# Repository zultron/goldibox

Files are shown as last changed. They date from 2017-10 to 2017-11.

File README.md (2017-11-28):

# Goldibox.  Not too hot, not too cold.

The Goldibox is an insulated box that maintains temperature using a
thermoelectric device and a controller.  Originally conceived to
incubate biological organisms that thrive best within a particular
maximum/minimum temperature range, it can both heat and cool to avoid
extremes, but still allow variability within a habitable "Goldilocks
zone":  not too hot, not too cold, but just right.

The Goldibox's smart controller exposes a remote, network-connected
graphical interface for setting temperatures, checking current state,
and viewing history through time series graphs.  Anyone may modify the
open-source control to add new features.

## Components

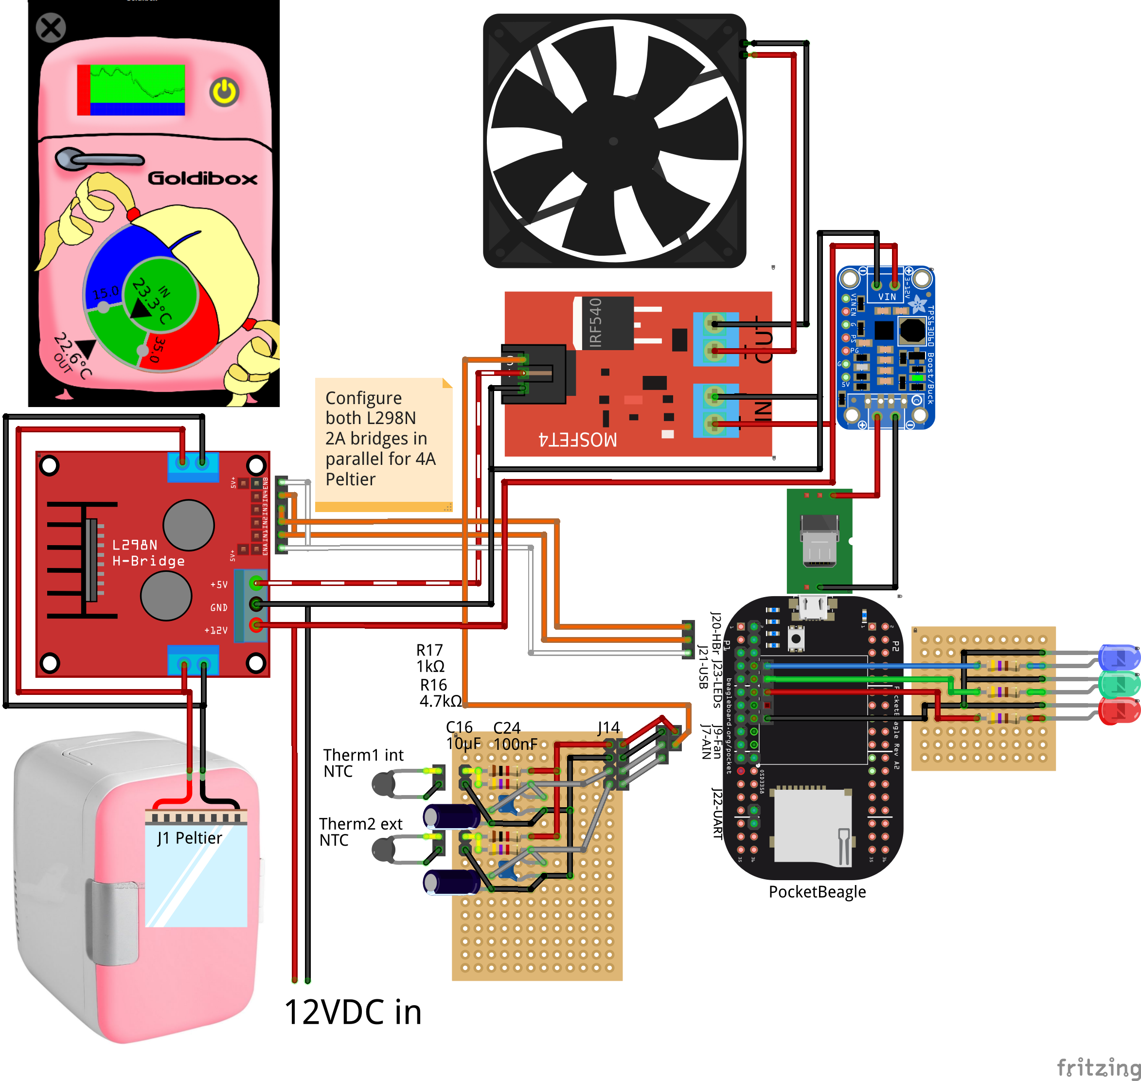
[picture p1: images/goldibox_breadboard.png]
Goldibox


The Goldibox is built from a portable fridge with a [Peltier
junction][wiki-peltier] that can be switched either to cool or to heat
by reversing the input voltage.

The Goldibox controller, a tiny [PocketBeagle][pocketbeagle] computer
that runs Debian, fits in the cramped space next to the Peltier
junction fan and heat sink.  It senses internal and external
temperatures through a pair of thermistors attachd to its analog
inputs, and it switches the Peltier junction and fan through an
H-bridge and a MOSFET, respectively, connected through GPIO digital
output pins.  See `BOM.md` for a list of hardware components, and
`fritzing/goldibox.fzz` for connecting them.

The [Machinekit][machinekit] software runs the configuration in this
repository:  some python user-space components in the `bin/`
directory, and HAL configuration in the `hal/` directory.  The
`goldibox-control` component decides whether to switch the Peltier
junction to cool, heat, or off, depending on the measured temperature
compared to the user's Goldilocks temperature settings.  The
`goldibox-logger` component logs to a RRD database, from which time
series charts are generated.

The `goldibox-control` component exposes a remote UI, used by the
`MachinekitClient` software, which can be downloaded for Android from
the Google Play store, and for Linux, Mac OS X and Windows directly
from the [QtQuickVCP][qqvcp] project.  The configuration in the `qml`
directory defines the simple user interface with thermostat controls
for the "too hot" and "too cold" zones, readouts for internal and
external temperature, a power control to enable and disable the
Goldibox, and a time series chart showing temperatures over the last
day.

# Running

Follow the instructions at [machinekit.io][machinekit] to download
and install a mini-SD card image with Machinekit.

Log into the BeagleBone, clone this repository, and `cd` into the
repository directory.

On the PocketBeagle, start the Goldibox control from the command line
(load the overlay file for non-system installs):

    # Install minimal apache and other config
    sudo make install MININSTALL=1
    # Start control
    bin/goldibox -o

The Goldibox should now be ready for control.  Start the
[MachinekitClient][qqvcp] and open the Goldibox app.

Alternatively, run a Goldibox simulated control and GUI in a Docker
container from the command line:

    # Start the container
    docker/qqvcp.sh
    # Install minimal apache and other config
    sudo make install MININSTALL=1
    # Start control
    bin/goldibox &
    # Start GUI
    MachinekitClient &

The Goldibox may be installed to the system so that it is run at every
boot:

    sudo make install
    sudo systemctl daemon-reload
    sudo systemctl enable goldibox
    sudo systemctl start goldibox

The `apache2` package must be installed and the web server running for
the time-series chart to work.

# Installing the PocketBeagle

See the jumble of notes in [NOTES.md](NOTES.md)

[wiki-peltier]: https://en.wikipedia.org/wiki/Thermoelectric_cooling
[pocketbeagle]: https://beagleboard.org/pocket
[machinekit]: http://www.machinekit.io/
[qqvcp]: https://github.com/qtquickvcp/QtQuickVcp

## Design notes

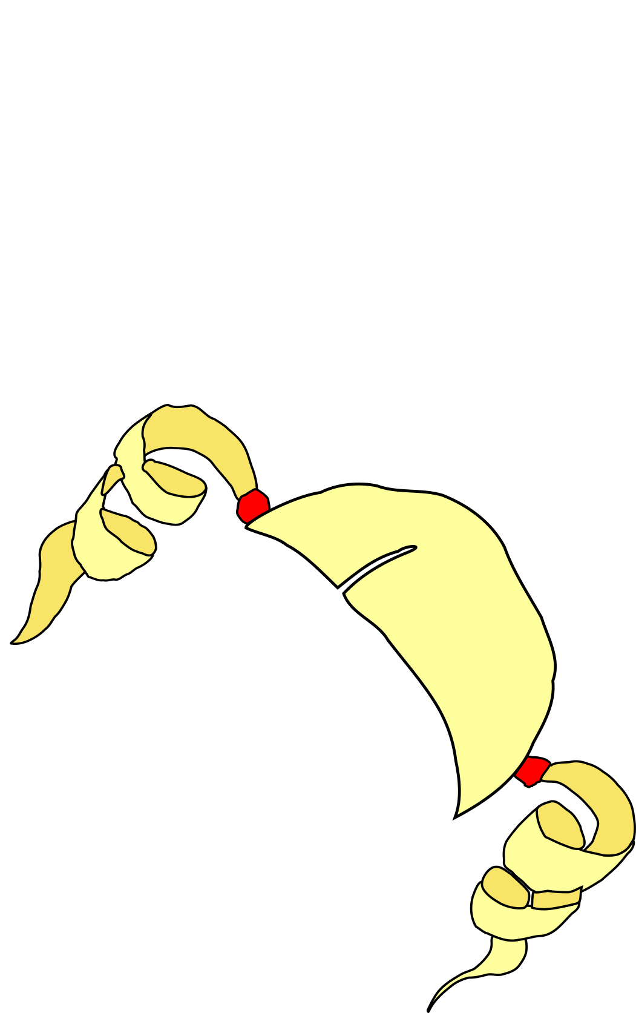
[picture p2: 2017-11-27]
qml/goldibox-remote/assets/locks.png

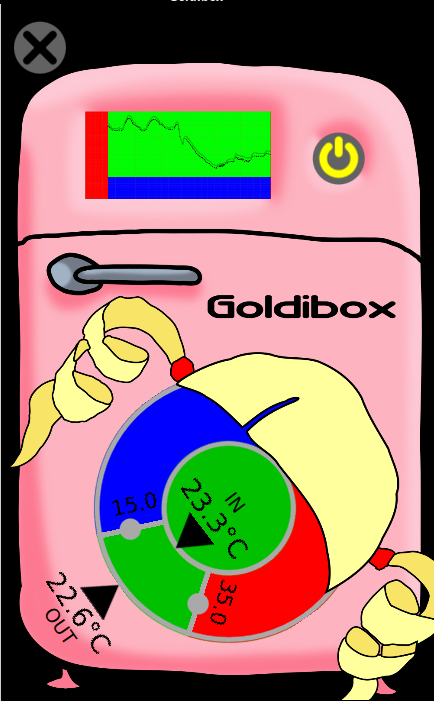
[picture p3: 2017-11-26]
images/gui-capture.png

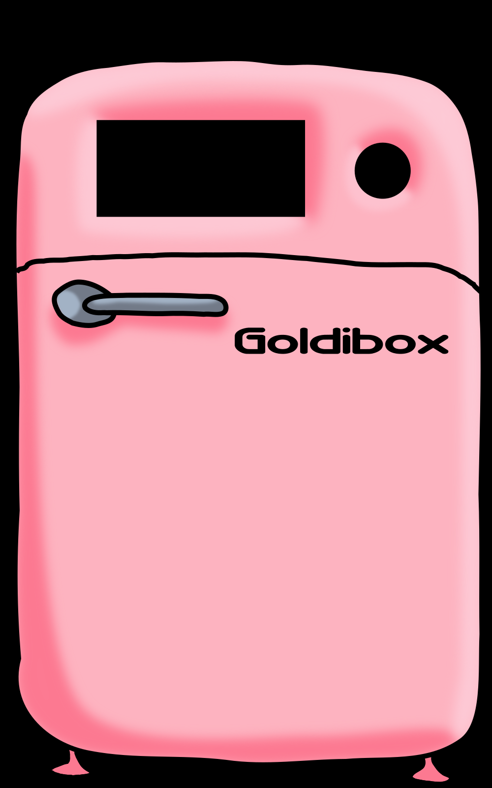
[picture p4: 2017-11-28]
qml/goldibox-remote/assets/background.png

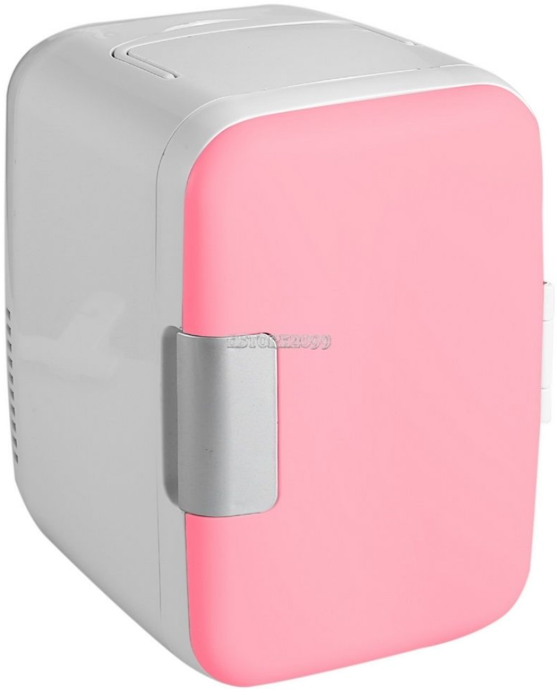
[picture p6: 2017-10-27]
fritzing/fridge.png

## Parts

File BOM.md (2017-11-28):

# Bill of materials

- Portable fridge
  - Search eBay for "portable fridge cooler warmer 110V", about $40
- Controller:
  - PocketBeagle computer
    - Shop official distributors, about $25
  - Micro SD card, class 10, 4GB or more, for PocketBeagle
    - About $10
  - [USB type A breakout module][usb-breakout], for PocketBeagle
    - Search eBay for "USB type A breakout module", about $5
  - USB WiFi adapter for networking
    - Look for a Raspberry Pi-compatible model, about $10
  - DC to 5VDC converter, provides 5V power to PocketBeagle
    - Search eBay for "DC step-down converter", about $5
- Power electronics:
  - H-bridge module for controlling Peltier
    - This project uses an L298N; you may find newer and better
      substitutes
    - Search eBay for "L298N motor driver module", about $5
  - MOSFET module for controlling fan
    - Search eBay for "Mosfet Arduino module", about $8
- Temperature sensing electronics:
  - Thermistor, 2 ea., 10k ohm at 25 deg. C.
    - Search eBay for "10k thermistor"
  - Resistors and capacitors:
    - Junk box, or eBay; see fritzing model for values
- Other parts:
  - Thermagon 6100 heat-conductive pad for conducting heat from fridge
    to internal thermistor
  - Header wires and solder
  - Heat-shrink tubing and custom-crimped connectors improve appearance

[usb-breakout]: https://github.com/zultron/fritzing-parts/tree/master/pocketbeagle-usb-type-a

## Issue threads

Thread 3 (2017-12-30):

Add fan delay

zultron, 2017-12-30:
There should be a configurable delay for the fan.  With zero hysteresis and the inherent instability of the thermistors, the Peltier may switch on and off quickly.  That's ok, but the fan should stay on a bit longer.

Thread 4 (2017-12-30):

Expose new settings

zultron, 2017-12-30:
- hysteresis
- fan delay
- thermistor error correction

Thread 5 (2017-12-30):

Add thermistor error correction

zultron, 2017-12-30:
Thermistors may be off a few degrees out of the box.  Add configurable error parameters, added to value, to calibrate both internal and external sensors.

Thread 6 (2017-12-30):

Add PID component to temp control

zultron, 2017-12-30:
Currently, the temp control is a simple switch, to which hysteresis can be added.  The temperature fluctuates above e.g. the min setting, +/- one degree, averaging one degree above the setting.  The fluctuation and chronic error might be optimized with a PID control.

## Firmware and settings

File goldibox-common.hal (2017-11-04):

# ################################################
# Goldibox comp
# ################################################

# Load userland comp
loadusr -Wn goldibox-control ./goldibox-control.py

# Inputs
# - Min/max/internal temp settings
net temp-min                        => goldibox-control.temp-min
net temp-max                        => goldibox-control.temp-max
net temp-int                        => goldibox-control.temp-int
# - Hysteresis
net hysteresis                      => goldibox-control.hysteresis
# - Enable
net enable                          => goldibox-control.enable
# - Shut down
net shutdown                        => goldibox-control.shutdown

# Outputs
# - On/off switch
net switch-on                       <= goldibox-control.switch-on
# - Heat/cool selector switch (1/0)
net switch-heat                     <= goldibox-control.switch-heat
# - Error
net error                           <= goldibox-control.error


# ################################################
# Peltier and fan out signals
# ################################################

# LUTs for on/off switch and heat/cool selector logic
newinst lut5 heat-on
addf heat-on                        main-thread
newinst lut5 cool-on
addf cool-on                        main-thread

# Peltier heat/cool LUT
# http://linuxcnc.org/docs/devel/html/man/man9/lut5.9.html
#
# on/1	heat/0	| heat	cool	| h val | c val
# 0	0	| 0	0	|	|
# 0	1	| 0	0	|	|
# 1	0	| 0	1	|	|   0x4
# 1	1	| 1	0	|   0x8	|
#                                 ----- | -----
setp heat-on.function               0x8
setp cool-on.function                       0x4

# Peltier heat LUT
# - Inputs
net switch-on                       => heat-on.in-1
net switch-heat                     => heat-on.in-0
# - Output to GPIO
net heat-on                         <= heat-on.out

# Peltier cool LUT
# - Inputs
net switch-on                       => cool-on.in-1
net switch-heat                     => cool-on.in-0
# - Output to GPIO
net cool-on                         <= cool-on.out


# ################################################
# Logger comp
# ################################################

# Load userland comp
loadusr -Wn goldibox-logger ./goldibox-logger.py

# Inputs
# - Temperatures
net temp-int                        => goldibox-logger.temp-int
net temp-ext                        => goldibox-logger.temp-ext
net temp-min                        => goldibox-logger.temp-min
net temp-max                        => goldibox-logger.temp-max
# - Enable/error/heat/cool
net error                           => goldibox-logger.error
net enable                          => goldibox-logger.enable
net heat-on                         => goldibox-logger.cool
net cool-on                         => goldibox-logger.heat
# - Shut down
net shutdown                        => goldibox-logger.shutdown


# ################################################
# Shutdown plumbing
# ################################################

# Latch the momentary shutdown button to a shutdown signal
newinst or2 shutdown
addf shutdown                       main-thread

# Shutdown latch
net shutdown                        <= shutdown.out
net shutdown                        => shutdown.in0
net shutdown-button                 => shutdown.in1

# Signal run.py
net shutdown                        => goldibox-run.shutdown

# ################################################
# Run
# ################################################

# Start threads
start

# Start haltalk server after everything is initialized or binding the
# remote components on the UI might fail
loadusr -W haltalk

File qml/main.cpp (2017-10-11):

/****************************************************************************
**
** Copyright (C) 2014 Alexander Rössler
** License: LGPL version 2.1
**
** This file is part of QtQuickVcp.
**
** All rights reserved. This program and the accompanying materials
** are made available under the terms of the GNU Lesser General Public License
** (LGPL) version 2.1 which accompanies this distribution, and is available at
** http://www.gnu.org/licenses/lgpl-2.1.html
**
** This library is distributed in the hope that it will be useful,
** but WITHOUT ANY WARRANTY; without even the implied warranty of
** MERCHANTABILITY or FITNESS FOR A PARTICULAR PURPOSE. See the GNU
** Lesser General Public License for more details.
**
** Contributors:
** Alexander Rössler @ The Cool Tool GmbH <mail DOT aroessler AT gmail DOT com>
**
****************************************************************************/
#include <QApplication>
#include <QQmlApplicationEngine>

int main(int argc, char *argv[])
{
    QApplication app(argc, argv);

    QQmlApplicationEngine engine;
    engine.addImportPath(QStringLiteral("imports"));
    engine.addImportPath(QStringLiteral("assets:/imports"));
    engine.load(QUrl(QStringLiteral("qrc:///main.qml")));

    return app.exec();
}

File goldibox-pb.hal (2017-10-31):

#!/usr/bin/env halrun
# ################################################
#
# Goldibox PocketBeagle HAL configuration
#
# http://linuxcnc.org/docs/devel/html/man/man1/halcmd.1.html
#
# ################################################
# Load and plumb comps
# ################################################

# ################
# Thermistor
# - 10k thermistors with 1k pull-up resistor:  internal on AIN0, external on AIN1
#     https://github.com/machinekit/machinekit/blob/master/src/hal/user_comps/hal_temp_bbb.py

# - Load thermistor comp
loadusr -Wn therm hal_temp_bbb -n therm -c 00:TR91,01:TR91 -b CRAMPS -r 1000
# - Internal temp signal
net temp-int                        <= therm.ch-00.value
net temp-ext                        <= therm.ch-01.value

# ################
# Threads

# - One slow thread
loadrt threads name1=main-thread period1=10000000

# ################
# PocketBeagle GPIOs
#     http://linuxcnc.org/docs/devel/html/man/man9/hal_bb_gpio.9.html
# - pinouts
#     http://beagleboard.org/support/bone101

loadrt hal_bb_gpio board=PocketBeagle output_pins=102,104,106,108,110,112,120
addf bb_gpio.read                   main-thread
addf bb_gpio.write                  main-thread

# - Peltier heat/cool/enable
net heat-on                         => bb_gpio.p1.out-02
net cool-on                         => bb_gpio.p1.out-04
net enable                          => bb_gpio.p1.out-06

# - Fan
net switch-on                       => bb_gpio.p1.out-20

# - LEDs
net cool-on                         => bb_gpio.p1.out-08
net enable                          => bb_gpio.p1.out-10
net heat-on                         => bb_gpio.p1.out-12

# ################################################
# Load common HAL config
# ################################################

source goldibox-common.hal

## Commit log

2017-10-09 HAL config: fix comp path; start threads
    [mk-incubator.hal]
2017-10-09 setup.sh: don't fail when config-pin does
    config-pin doesn't like to be run twice
2017-10-09 HAL config: fix typo
    [mk-incubator.hal]
2017-10-09 HAL config: fix setting enable=1
    [mk-incubator.hal]
2017-10-09 Add and plumb 'exit' pin to incubator comp
    [mk-incubator.hal]
2017-10-09 HAL config: add pin aliases
    [mk-incubator.hal]
2017-10-09 HAL config: wait for incubator comp to exit & shut down
    [mk-incubator.hal]
2017-10-09 HAL config: prettify comments
    [mk-incubator.hal]
2017-10-09 HAL config: remove aliases
    Apparently "deprecated" in the MK docs means "long gone"
    [mk-incubator.hal]
2017-10-09 component: print progress messages
2017-10-09 HAL config: Fix exit signal
    Seems h['exit'] is actually a function that can't be overridden, but
    also doesn't produce an error when one tries
    [mk-incubator.hal]
2017-10-09 config: straighten out peltier +/-
    [mk-incubator.hal]
2017-10-09 Make mk-incubator.hal executable
    [mk-incubator.hal]
2017-10-09 Add Fritzing schematics
    [incubator.fzz]
2017-10-09 Update fridge schematic before deleting
2017-10-09 Remove mk-fridge-schematic.svg
    Fritzing file is now authoritative
2017-10-09 Updated incubator.fzz
    Pretty close to final form now
    [incubator.fzz]
2017-10-09 Add documentation
    - README
    - Links in HAL file and setup script
    [mk-incubator.hal]
2017-10-09 better status messages; hysteresis; logic changes
    - Clean up status messages
    - Display messages on state change
    - Clean up logic to make better messaging possible
    - Clean up logic to make hysteresis possible
    - Only sample once per cycle to avoid any funny race conditions
    - Add hysteresis
    [mk-incubator.hal]
2017-10-09 Switch output pins to P8 connector
    [incubator.fzz, mk-incubator.hal]
2017-10-09 comp: fix reversed heat/cool
2017-10-09 Fix fan signal polarity
    Fan signals are mirror image of peltier signals
    [mk-incubator.hal]
2017-10-09 Update Fritzing cosmetics
    [incubator.fzz]
2017-10-09 Update Fritzing file for perfboard and three thermistors
    [incubator.fzz]
2017-10-09 Move fritzing stuff to its own directory
    [incubator.fzz]
2017-10-09 README: note config-pin location
2017-10-10 Add simulator mode
    Rename comps
    [incubator-bb.hal, incubator-sim.hal]
2017-10-11 Initial commit of remote comp attempt
    [incubator-sim.hal]
2017-10-11 Update fritzing with pocketbeagle
    [incubator.fzz]
2017-10-12 Update fritzing with headers
    [incubator.fzz]
2017-10-14 Update fritzing
    [incubator.fzz]
2017-10-20 FIXME commit more fritzing and icon files than needed
    [goldibox.fzz, incubator.fzz]
2017-10-20 incubator-bb.hal and setup.sh: redo pins for PocketBeagle
    [incubator-bb.hal]
2017-10-25 incubator-bb.hal: Update thermistors
    Use two TR91 10k NTC thermistor with 1k pull-up resistors
    [incubator-bb.hal]
2017-10-25 goldibox.fzz: Updates
    - Trim to two thermistors
    - Add USB and console headers
    [goldibox.fzz]
2017-10-25 Update circuit with LEDs
    - Added LEDs
    - Added PB power via micro USB
    - Grounds moved around
    [goldibox.fzz]
2017-10-25 pb_goldibox.dts: add LED pins
2017-10-25 fritzing cleanups
    [goldibox.fzz]
2017-10-26 Split out common HAL config; add LEDs
    [goldibox-common.hal, goldibox-pb.hal, goldibox-sim.hal]
2017-10-26 goldibox-common.hal: fix error shutting down
    [goldibox-common.hal]
2017-10-26 goldibox-pb.hal: remove forgotten debug command
    [goldibox-pb.hal]
2017-10-26 Add logger component
    [goldibox-common.hal]
2017-10-26 goldibox-pb.hal: fix peltier signal polarity
    [goldibox-pb.hal]
2017-10-27 goldibox-common.hal: allow goldibox-settings to shut down gracefully
    [goldibox-common.hal]
2017-10-27 Add goldibox-settings comp
    Persist settings between runs
    [goldibox-common.hal]
2017-10-27 goldibox-common.hal: silence warnings
    - Restore config before starting control comp
    - Do a dumb sleep instead of waitusr to allow comps to exit
    [goldibox-common.hal]
2017-10-27 Update logo: gauge w/locks on fridge
    [goldibox.fzz]
2017-10-27 Fritzing and graphics: update fridge pic
    Pink
    [goldibox.fzz]
2017-10-28 goldibox-sim.hal: FIXME temp. disable remote comp
    [goldibox-sim.hal]
2017-10-28 Do away with setup.sh in favor of goldibox-overlay-pb.bbio
    [goldibox-pb.hal]
2017-10-28 goldibox-pb.hal: Don't bother with config-pin
    .dts file works correctly now at boot time
    [goldibox-pb.hal]
2017-10-28 sim: restore fan; remove f-cool; change f-heat to f-on
    Fan used to be driven by H-bridge; fix and simplify stuff after change
    to mosfet control
    [goldibox-sim.hal]
2017-10-28 goldibox-sim.hal: set defaults for *-incr signals
    These defaults limit status messages to about 5 seconds or so
    [goldibox-sim.hal]
2017-10-28 Move remote comp to common HAL config
    [goldibox-common.hal, goldibox-sim.hal]
2017-10-28 Update icon
    - Pink fridge & other visual updates
    - Simplified graphics
    - Update README and fritzing
    - Rename icon dir to images
    [goldibox.fzz]
2017-10-30 Update remote comp framework
    - Move run and shutdown portions from `goldibox-common.hal`
    - `run.py` script should take care of this
    - Reattach rcomp output pins to control signals
    - Remove sim-related pins from rcomp
    - These can be set elsewhere
    - Fix glitches in sim HAL config
    - Update icon
    - Update qml description
    [goldibox-common-run.hal, goldibox-common.hal, goldibox-pb.hal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]
2017-10-30 Rename comps
    - Rename comps goldibox to goldibox-control, rcomp to goldibox-remote
    - Fix things for remote operation
    - Print meaningful error message in run.py
    [goldibox-common.hal]
2017-10-31 Change run.sh +: closer to working anddemo config
    A working anddemo config was working, with changes like these. Still
    broken, though....
    [goldibox-common-run.hal, goldibox-common.hal, goldibox-sim.hal]
2017-10-31 First working remote comp
    It's ugly, but it connects. Seems the problems were:
    - HalApplicationWindow has to match remote comp name
    - Remote comp has to be run from run.py
    - Why is python environment different?
    Misc.:
    - Change HalLabel to Label to silence errors
    - Connect forgotten widgets to silence errors
    - Plumb external temp pin
    - Remove goldibox-common-run.hal
    - Change name of thread
    [goldibox-common-run.hal, goldibox-common.hal, goldibox-sim.hal]
2017-10-31 goldibox-pb.hal: Update thread name + comments
    - Update thread name after remote GUI changes
    - Update comments
    [goldibox-pb.hal]
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2017-10-31 Spruce up UI & fix outside/ext ugliness
    - Remove hysteresis and switch-heat signals
    - These won't be in final version
    - Rename everything outside-temp to temp-ext
    - This mixup was causing breakage
    - Move sim defaults to where they won't be clobbered
    - Setting signal and netting it later causes it to be cleared
    - Update UI
    - Remove unused controls
    - Rearrange controls
    - Change LED colors and add labels for clarity
    [goldibox-common.hal, goldibox-sim.hal]
2017-10-31 goldibox-common.hal: no-op comments
    [goldibox-common.hal]
2017-10-31 Remove separate LED signals
    [goldibox-common.hal, goldibox-pb.hal]
2017-10-31 Fix control directions in sim
    [goldibox-common.hal]
2017-10-31 goldibox-pb.hal: fix heat/cool direction
    [goldibox-pb.hal]
2017-11-01 Fix shutdown button
    - Latch shutdown button to shutdown signal
    - Add comp and shutdown signal to run.py
    - Add shutdown signal to sim-temp comp
    [goldibox-common.hal, goldibox-sim.hal]
2017-11-01 Attempt to persist settings
    [goldibox-common.hal]
2017-11-04 qqvcp.sh: -h switch for host networking
    - Optionally run container in host networking mode for external client
    connectivity
    - Use getopts
2017-11-04 Fix restoring saved state on startup
    Remote comp pin setting gets clobbered when netting signal in .hal
    file, so net in comp instead.
    At the same time, rework the remote comp to reduce mess; this meant
    renaming p-cool and p-heat signals.
    [goldibox-common.hal, goldibox-sim.hal]
2017-11-05 Make system installable
    - Add Makefile
    - Separate bin, var, etc, share directories
    - Add common python lib to find config and print messages
    - Make each path configurable from config file
    [common.hal, pb.hal, sim.hal]
2017-11-05 Switch to HalKnob
    HalDial type is deprecated
    https://github.com/qtquickvcp/QtQuickVcp/issues/218#issuecomment-341887253
2017-11-13 Non-working attempt at fixing imports
    Working:
    - Qt Designer finds imports
    - Qt Designer renders `Goldistat.qml` correctly
    - Build works
    Not working:
    - Qt Designer does not render `debug.qml` correctly
    - App will not run (no rules to install resources into build dir?):
    QQmlApplicationEngine failed to load component
    qrc:///goldibox-remote/debug.qml:26 module "Goldistat" is not installed
    [main.cpp]
2017-11-14 Add initial PowerButton widget
2017-11-14 PowerButton: Convert to Button with Style
    Re-use QtQuick.Controls.Button, and put circle and canvas into a
    ButtonStyle background.
2017-11-25 qml: Re-orient power button
2017-11-25 qml: Add exit button
2017-11-26 qml: Light power button yellow when on
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2017-11-26 Plumb Goldibox remote app
    - Disable unused remote comp pins to fix failure
    - Fix settings pin directions to fix failure
    - Remove `debug.qml` to fix confusion
    - Update `goldibox-remote.qml`
    [main.cpp]
2017-11-26 Update all images everywhere
    [goldibox.fzz]
2017-11-28 qml: Show time series chart from server
    Add live time series mini-chart, updated periodically, as button that
    opens browser to main chart page
    - Add CGI config to apache
    - Add CGI to generate .png
    - Add TimeSeries QML
2017-11-28 qml background image: black blank placeholders for button, graph
